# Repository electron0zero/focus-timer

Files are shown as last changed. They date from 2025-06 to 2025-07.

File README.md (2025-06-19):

# Focus Timer

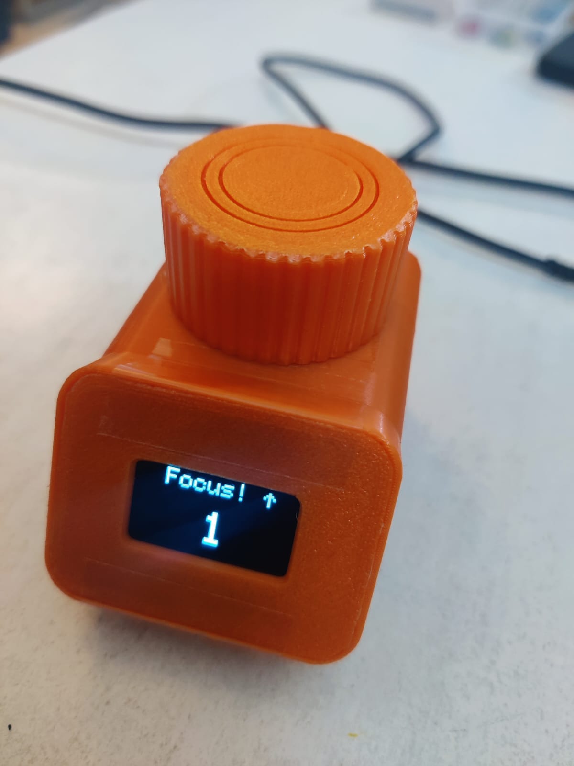
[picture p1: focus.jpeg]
Flow Counter showing focus minutes
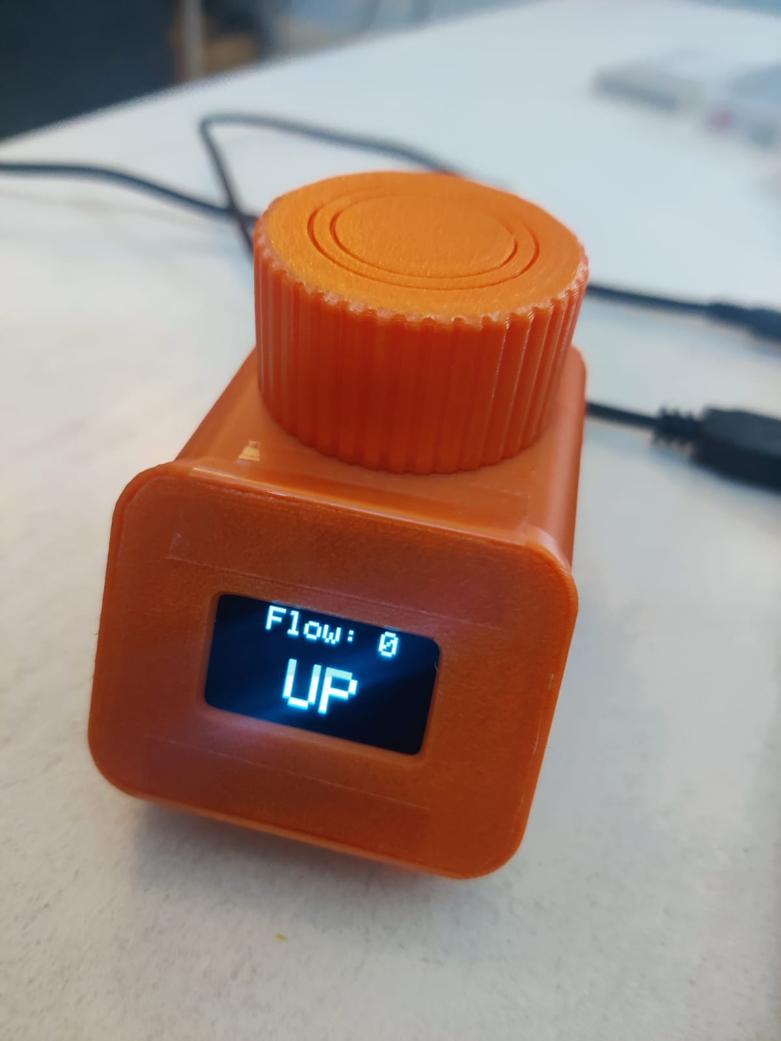
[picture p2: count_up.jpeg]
Flow Counter showing up counting
 

A customized version of [Project IGOR](https://github.com/UrbanCircles/igor), modified to suit my personal preferences and needs and the components I can easily find in major Indian hobby and electronics websites.

This is mostly the same as the original IGOR project, but with some tweaks to code and the PIN mapping for my specific hardware setup.

If you want to build your own version, you can use this as a starting point.

This would cut down the trial and error time for you, if your hardware is different from the original project and more close to mine.

## Features

Mostly same as the original IGOR project, with some minor tweaks, [see original](https://github.com/UrbanCircles/igor#its-simple-features-v1)

See this [video from the original project](https://www.youtube.com/watch?v=Wko0zgRGtPI) for a demo of the features.

## Hardware
- D1 Mini (ESP8266) - Sourced from robu.in
- 0.96" OLED Display (SSD1306)
- Rotary Encoder (HW-040)

## BOM

| Component | Quantity | Price (INR) | Robu.in Item and Link |
|---|---|---|---|
| D1 Mini (ESP8266) | 1 | ₹ 182.00  | D1 Mini V2 NodeMcu 4M Bytes Lua WIFI Internet Of Things Development Board Based ESP8266 - [link](https://robu.in/product/d1-mini-v2-nodemcu-4m-bytes-lua-wifi-internet-of-things-development-board-based-esp8266/) |
| 0.96" OLED Display (SSD1306) | 1 | ₹ 240.00 | 0.96″ OLED Display Module – SPI/I2C – 128×64 – 7 Pin (Blue) - [link](https://robu.in/product/0-96-oled-display-module/) |
| Rotary Encoder (HW-040) | 1 | ₹ 49.00 | M274 360 Degree Rotary Encoder Brick Sensor Module - [link](https://robu.in/product/m274-360-degree-rotary-encoder-module-brick-sensor/)  |
| Jumper Wires (Dupont) | 1 | ₹ 145.53 | 20 CM 40 Pin Dupont Cable Male/Male, Male/Female, Female/Female Cable Combo - [link](https://robu.in/product/20-cm-40-pin-dupont-male-male-male-female-female-female-cable-combo/) |

Total BOM Cost: ₹ 616.53 INR

> NOTE: to encoder I bought doesn't have a screw on the stem and it required a standoff to make it work, so if you don't want the hassle, buy an encoder that has a screw on stem so you can screw it to the box. it makes it easy to assemble and way better then the standoff workaround.

**Miscellaneous Items**

Breadboard, Jumper Wires(Dupont), 10k OHM resister, Soldering Station, etc.

## Pin Mapping and Wiring

The pin mapping is as follows:

#### OLED Pin Mapping

| OLED Pin | D1 Mini Pin | Comments |
|---|---|---|
| GND | G (GND) | Ground |
| VDD | 3V3 | Power supply (use 3.3V only) |
| SCK | D5 | SPI Clock — hardware SPI line, do not reuse |
| SDA | D7 | SPI Data — hardware SPI line, do not reuse |
| RES | D6 | OLD reset PIN |
| DC | D3 | Has pull-up; LOW at boot can cause boot issues — OK with INPUT_PULLUP |
| CS | D8 | Must be LOW at boot — OLED CS is typically LOW anyway |

#### Rotary Encoder Pin Mapping

| Encoder Pin | D1 Mini Pin | Comments |
|---|---|---|
| CLK | D1 | INT-capable — safe |
| DT | D2 | INT-capable — safe |
| SW | D0 | No internal pull-up — needs external 10KΩ pull-up |

**NOTE**
- Don't use D4, it's connected to the onboard blue LED so leave D4 Pin unused to not interfere with the built in LED.
- Don’t use D7, D5 for anything other than SPI for OLED when using hardware SPI. this OLED breakout board uses hardware SPI, so you must use the same pins as shown above.

#### wiring diagram

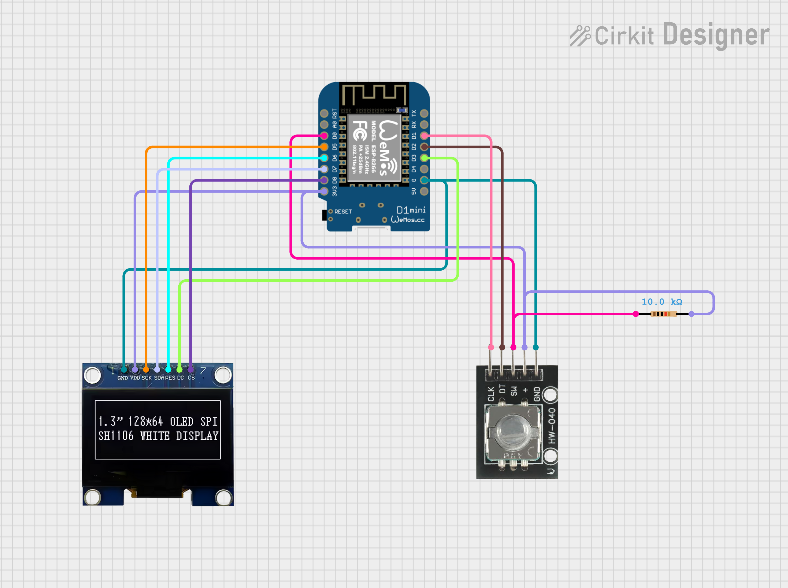
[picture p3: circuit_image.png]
wiring image


See [Focus Timer Wiring](https://app.cirkitdesigner.com/project/0dea471c-eeaa-448d-815e-7a7b2d2015ea) cirkitdesigner project for interactive wiring diagram.

## Microcontroller firmware

Load the firmware from the focus_timer.ino file into your D1 Mini (ESP8266) using the Arduino IDE.

Watch this video to see how to setup Arduino IDE for ESP8266: [Get Started With A D1 Mini (ESP8266) In Under 5 Minutes!](https://www.youtube.com/watch?v=WnRk8w7SyTo)

If the firmware does not work as expected, or some components are not working, you can try to [debug_code](./debug_code/) firmware and try to debug with logs in the serial monitor in the Arduino IDE.

## 3D Printed Parts - Case

I used a [3D files](https://github.com/UrbanCircles/igor/tree/main/3D%20Parts) from the original project, and printed it on my printer.

Same file can be found on [Printables](https://www.printables.com/model/1019283-project-igor-open-source-offline-loyal-cheerful-fo)

My encoder HW-040 didn't come with a screw stem to attach the encoder knob to the case, so I modelled a custom standoff to keep the encoder pcb in place and allow the encoder knob to be attached to the case.

if you want to print the standoff, you can find stl file in the repo, along with the [openSCAD](https://openscad.org/index.html) file to modify it if needed: [hw-040-standoff.scad](./hw-040-standoff.scad) and [hw-040-standoff.stl](./hw-040-standoff.stl)

If you don't own a 3D printer, ask your friends who have one or use 3D printing services from robu.in or other similar websites.

## Assembly & User Guide

See Original [Assembly](https://github.com/UrbanCircles/igor#assembly) and [guide](https://github.com/UrbanCircles/igor#user-guide)

## Credits

Most of the code is from [Project IGOR by UrbanCircles](https://github.com/UrbanCircles/igor) with some modifications by me.

The original project is licensed under the MIT License, my debugging code and modifications are also licensed under the MIT License.

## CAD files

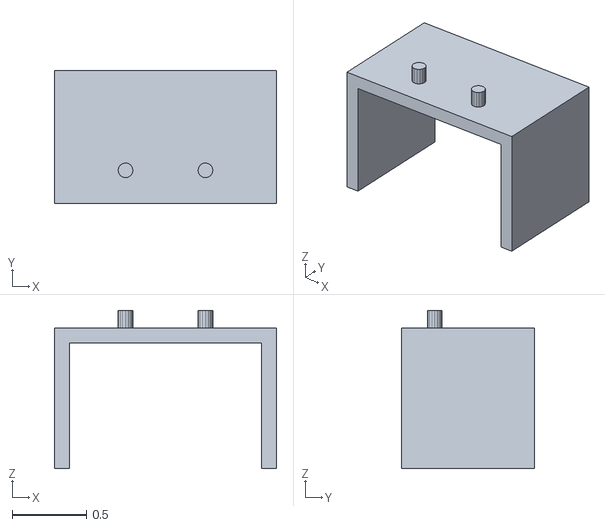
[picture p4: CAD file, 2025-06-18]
hw-040-standoff.stl
1.50 x 0.9 x 1.07

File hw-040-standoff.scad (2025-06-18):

// Parameters
leg_width = 0.10;           // Width of each leg
leg_depth = 0.90;           // Depth/thickness of each leg
leg_spacing = 1.3;         // Space between the two legs
table_height = 0.85;      // Height of the table top
top_thickness = 0.10;       // Thickness of the tabletop
pin_diameter = 0.10;       // Diameter of the alignment pins
pin_spacing = 0.54;        // Center-to-center spacing between pins
pin_height = 0.12;          // Height of alignment pins

// Build each leg
module leg(x_offset) {
    translate([x_offset, 0, 0])
        cube([leg_width, leg_depth, table_height]);
}

// Build tabletop
module tabletop() {
    translate([0, 0, table_height])
        cube([2 * leg_width + leg_spacing, leg_depth, top_thickness]);
}


// Build alignment pins on top
module pin(x_offset) {
    translate([x_offset, leg_depth * (1/4), table_height + top_thickness])
        cylinder(h = pin_height, d = pin_diameter, $fn = 16);
}


// Assemble standoff
union() {
    leg(0);
    leg(leg_width + leg_spacing);
    tabletop();

    // Pins, centered on tabletop
    pin((2 * leg_width + leg_spacing) / 2 - pin_spacing / 2);
    pin((2 * leg_width + leg_spacing) / 2 + pin_spacing / 2);
}

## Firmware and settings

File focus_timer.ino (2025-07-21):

#include <SPI.h>
#include <Adafruit_GFX.h>
#include <Adafruit_SSD1306.h>

//=========================================
// Hardware PIN Definitions / Mappings
// NOTE: make sure harware wiring matches this pin mapping

// OLED pin mapping for Display with Driver IC: SSD1306
// Display Source: https://robu.in/product/0-96-oled-display-module/#tab-description
// In my testing it only supports SPI and I2C doesn't work even tho it says I2C is supported.
//
// Pin connections for SPI
// | OLED Pin   | ESP8266 Pin | Notes                |
// | ---------- | ----------- | -------------------- |
// | GND        | GND         | Ground               |
// | VDD        | 3.3V        | Power (3.3V)         |
// | SCK (CLK)  | D5 (GPIO14) | SPI Clock            |
// | SDA (MOSI) | D7 (GPIO13) | SPI Data             |
// | RES        | D6 (GPIO12) | Reset                |
// | DC         | D3 (GPIO0)  | Data/Command select  |
// | CS         | D8 (GPIO15) | Chip select          |
//
// Don’t use D7, D5 for anything other than SPI for OLED when using hardware SPI.
// we are using hardware SPI, so you must not interfere with D5 (SCK) and D7 (MOSI),
// which are automatically used by SPI.
//
// see https://lastminuteengineers.com/wemos-d1-mini-pinout-reference/ for the details
// on which can be used for what, and why.

// Working pin setup for OLED without interfering with the encoder pins and onboard LED
// Don't use D4, it's connected to the onboard blue LED so leave D4 Pin unused
#define OLED_CLK    D5  // GPIO14
#define OLED_MOSI   D7  // GPIO13
#define OLED_RESET  D6  // GPIO12 — safe
#define OLED_DC     D3  // GPIO0 — safe if pulled HIGH at boot (default with pull-up)
#define OLED_CS     D8  // GPIO15 — must be LOW at boot (OLED CS is typically LOW)

#define SCREEN_WIDTH 128
#define SCREEN_HEIGHT 64

// Init the disaply lib
Adafruit_SSD1306 display(SCREEN_WIDTH, SCREEN_HEIGHT,
                         &SPI, OLED_DC, OLED_RESET, OLED_CS);

// Rotary Encoder pin definitions (no conflict with OLED PINS)
// #define ENC_SW   D4  // GPIO2 (needs to be HIGH at boot, connected to FLASH button, boot fails if pulled LOW)
//
// D4 Pin is hard-wired to on board LED so each time the SW is pressed, the LED will on turned on.
// it can be a feature or a bug, I liked that it's indicating button press but you may not want that.
// if you don't want, use D0 ping with a pull up register to disable the onboard LED.
//
// IMP. NOTE for ENC_SW when using PIN D0: make sure the use a 10k pull up resister between SW and VCC (+ pin)
// of the encoder to pull SW pin high otherwise the button press will make SW LOW and it will be stuck LOW
#define ENC_SW   D0  // GPIO16 (no INT, OK for polling), needs a 10K register as pull up with 3.3V
#define ENC_DT   D2  // GPIO4 (INT-capable, safe)
#define ENC_CLK  D1  // GPIO5 (INT-capable)


//=========================================
int flowMinutes = 0;   // Total flow minutes
int menuIndex = 0;     // 0 for UP, 1 for DOWN, 2 for Reset
String menuOptions[3] = {"UP", "DOWN", "Reset"};  // Label reset option as "Reset"
// for IDLE mode detection and display IDLE? text
unsigned long lastActivityTime = 0;  // For inactivity detection
const unsigned long inactivityLimit = 2 * 60000;  // 2 minutes in milliseconds

enum State { MENU, COUNTING_UP, COUNTING_DOWN, SELECTING_DOWN_DURATION, IDLE };
State currentState = MENU;

int countdownValue = 50;  // Default value for countdown
int initialCountdownValue = 50;  // Store the countdown value when selected
unsigned long previousMillis = 0;  // For counting logic
int elapsedMinutes = 0;
bool isCounting = false;

// IDLE mode extended behavior, display is turned off if we are in IDLE mode for 5 mins
const unsigned long displayOffTimeLimit = 5 * 60000;  // 5 minutes in milliseconds

unsigned long idleStartTime = 0;  // Track when IDLE mode starts
bool displayOff = false;  // Track if the display is off

// counter to know if the encoder was rotated or not, with direction
// We use following values:
// Clockwise = 1
// Counter Clockwise = -1
// No Rotation = 0
volatile int rotation = 0;
volatile bool rotated = false;
// volatile int counter = 0;

// Rotary encoder debounce variables
unsigned long lastInterruptTime = 0;
const unsigned long debounceDelay = 10;  // ms

// unsigned long lastRotaryTime = 0;
// const unsigned long rotaryDebounceDelay = 150;  // Faster debounce for rotary encoder

// Push button debounce and last state
unsigned long lastButtonDebounceTime = 0;
const unsigned long buttonDebounceDelay = 10;  // ms

// unsigned long buttonDebounceTime = 0;
// const unsigned long buttonDebounceDelay = 800;  // Debounce delay

volatile int lastClkState = HIGH;
volatile int lastDtState = HIGH;
bool lastButtonState = HIGH;

//=========================================
// Detect encoder rotation with Interrupts and debounce

void ICACHE_RAM_ATTR handleRotationState() {
  int clkState = digitalRead(ENC_CLK);
  int dtState = digitalRead(ENC_DT);

  // Only act when CLK changes and don't act on each Interrupt trigger
  if (clkState != lastClkState) {
    if (dtState != clkState) {
      // clockwise rotation happened
      rotation = 1;
      // counter++;
    } else {
      // counter clockwise rotation happened
      rotation = -1;
      // counter--;
    }
    rotated = true;
  }

  // Serial.print("Last ENC_DT: ");
  // Serial.print(lastDtState);
  // Serial.print(" ENC_DT: ");
  // Serial.print(dtState);
  // Serial.print(" Last ENC_CLK: ");
  // Serial.print(lastClkState);
  // Serial.print(" ENC_CLK: ");
  // Serial.print(clkState);
  // Serial.print(" counter: ");
  // Serial.println(counter);
  // Serial.print(" rotation: ");
  // Serial.println(rotation);
  // Serial.print(" rotated: ");
  // Serial.println(rotated);

  lastClkState = clkState;
  lastDtState = dtState;
}

void setup() {
  Serial.begin(115200);
  initEncoder();
  // attach Interrupt for encoder pins and handleRotationState
  attachInterrupt(digitalPinToInterrupt(ENC_CLK), handleRotationState, CHANGE);
  initDisplay();
  updateDisplay();

  Serial.println("Setup complete, starting loop...");
}

void loop() {
  unsigned long currentMillis = millis();

  // Handle rotary encoder input
  // rotation state is handled by handleRotation, called by Interrupt
  handleRotaryInput();

  // Handle button presses and states
  handleButtonPresses(currentMillis);

  // Handle counting logic
  handleCounting(currentMillis);

  // disable the idle mode feature
  // Handle inactivity
  handleInactivity(currentMillis);

  // reset rotation variables
  if (rotated) {
    rotated = false;
    // reset the rotation state if we rotated
    rotation = 0;
  }
}

//=========================================================
// Initialize hardware pins, and initialize the OLED display
void initEncoder() {
  // init encoder pins
  pinMode(ENC_SW, INPUT_PULLUP);
  pinMode(ENC_DT, INPUT_PULLUP);
  pinMode(ENC_CLK, INPUT_PULLUP);

  // log init state of encoder pins
  Serial.println("");
  Serial.println("Starting up...");
  Serial.print("Initial ENC_SW: ");
  Serial.println(digitalRead(ENC_SW)); // Should be HIGH with pullup
  Serial.print("Initial ENC_DT: ");
  Serial.println(digitalRead(ENC_DT)); // Should be HIGH with pullup
  Serial.print("Initial ENC_CLK: ");
  Serial.println(digitalRead(ENC_CLK)); // Should be HIGH with pullup

}

void initDisplay() {
  if (!display.begin(SSD1306_SWITCHCAPVCC, 0x3C)) {
    Serial.println("SSD1306 init failed");
    for (;;); // Halt
  }
  Serial.println("Display initialized.");

  // print READY for 1s to show that it's ready
  display.clearDisplay();
  display.setTextSize(4); // Large text
  display.setTextColor(WHITE);
  display.setCursor(0, 20); // print the text center of display
  display.println("READY");
  display.display();

  // wait 1 second with ready before we clear the display
  delay(1000);
  display.clearDisplay();
}

//=========================================================
// Update the OLED display with the current state
void updateDisplay() {
  display.setTextColor(WHITE);
  display.clearDisplay();

  // Display top row
  String topRowText;

  if (currentState == COUNTING_UP) {
    topRowText = "Focus! \x18";  // Focus with upward triangle for counting UP
  } else if (currentState == COUNTING_DOWN) {
    topRowText = "Focus! \x19";  // Focus with downward triangle for counting DOWN
  } else {
    // Display total flow minutes as hours and mins when not counting
    int hours = flowMinutes / 60;
    int minutes = flowMinutes % 60;
    char buffer[16];
    // using snprintf to padd the hour and seconds
    snprintf(buffer, sizeof(buffer), "Flow %02d:%02d", hours, minutes);
    topRowText = String(buffer);
  }

  int topRowTextWidth = topRowText.length() * 12;  // TextSize 2, so 12 pixels per char
  int topRowX = (128 - topRowTextWidth) / 2;  // Center the text on the top row

  display.setTextSize(2);  // Larger size for top row
  display.setCursor(topRowX, 0);  // Centered on top row
  display.print(topRowText);

  // Display main row (menu or counting values)
  String mainRowText;

  if (currentState == MENU) {
    mainRowText = menuOptions[menuIndex];  // Display UP, DOWN, or Reset in the menu
  } else if (currentState == COUNTING_UP) {
    mainRowText = String(elapsedMinutes);  // Display counting up minutes
  } else if (currentState == COUNTING_DOWN || currentState == SELECTING_DOWN_DURATION) {
    mainRowText = String(countdownValue);  // Display countdown minutes
  } else if (currentState == IDLE) {
    mainRowText = "IDLE?";
  }

  int mainRowTextWidth = mainRowText.length() * 24;  // TextSize 4, so 24 pixels per char
  int mainRowX = (128 - mainRowTextWidth) / 2;  // Calculate centered X position

  display.setTextSize(4);  // Larger size for main row
  display.setCursor(mainRowX, 30);  // Centered on main row
  display.print(mainRowText);

  display.display();  // Show the updated display
}

//===========================================
// Detect encoder button presses with debounce
bool buttonPressed() {
  bool currentState = digitalRead(ENC_SW);
  // Serial.print("called buttonPressed, currentState: ");
  // Serial.println(currentState);

  if (lastButtonState == HIGH && currentState == LOW && (millis() - lastButtonDebounceTime > buttonDebounceDelay)) {
    Serial.println("push button pressed...");
    lastButtonDebounceTime = millis();
    lastButtonState = currentState;
    return true;
  }

  lastButtonState = currentState;
  return false;
}

//=========================================================
// Handle button presses and manage state transitions
void handleButtonPresses(unsigned long currentMillis) {
  if (!buttonPressed()) return;

  switch (currentState) {
    case MENU:
      if (menuIndex == 0) {  // UP selected
        startCountingUp();
      } else if (menuIndex == 1) {  // DOWN selected
        startSelectingDownDuration();
      } else if (menuIndex == 2) {  // Reset selected
        resetFlowMinutes();  // Reset the total focus time to 0
      }
      break;

    case SELECTING_DOWN_DURATION:
      confirmCountdownSelection();
      break;

    case COUNTING_UP:
      stopCountingUp();
      break;

    case COUNTING_DOWN:
      stopCountingDown();
      break;
  }
  updateDisplay();
}

//=========================================================
// Start counting up
void startCountingUp() {
  currentState = COUNTING_UP;
  elapsedMinutes = 0;
  isCounting = true;
  lastActivityTime = millis();  // Reset inactivity timer
  selectConfirm();
  Serial.println("Counting UP started.");
}

//=========================================================
// Start selecting the countdown duration
void startSelectingDownDuration() {
  currentState = SELECTING_DOWN_DURATION;
  countdownValue = 50;
  lastActivityTime = millis();  // Reset inactivity timer
  Serial.println("Selecting DOWN duration.");
}

//=========================================================
// Confirm countdown selection and start counting down
void confirmCountdownSelection() {
  initialCountdownValue = countdownValue;
  currentState = COUNTING_DOWN;
  isCounting = true;
  selectConfirm();
  lastActivityTime = millis();  // Reset inactivity timer
  Serial.print("Counting DOWN started with "); Serial.print(countdownValue); Serial.println(" minutes.");
}

//=========================================================
// Stop counting up and return to menu
void stopCountingUp() {
  flowMinutes += elapsedMinutes;
  successAnimation();
  currentState = MENU;
  isCounting = false;
  Serial.println("Counting UP stopped. Returning to MENU.");
}

//=========================================================
// Stop counting down and return to menu
void stopCountingDown() {
  flowMinutes += (initialCountdownValue - countdownValue);
  successAnimation();
  currentState = MENU;
  isCounting = false;
  Serial.println("Counting DOWN stopped. Returning to MENU.");
}

//=========================================================
// Reset the total flow minutes counter to 0
void resetFlowMinutes() {
  flowMinutes = 0;
  Serial.println("Flow minutes reset to 0.");
  successAnimation();
  updateDisplay();  // Update the display to show the reset value
}

//=========================================================
// Handle counting up or down logic
void handleCounting(unsigned long currentMillis) {
  // no-op if we are not counting or 1 minute has not passed since we counted
  if (!isCounting || (currentMillis - previousMillis < 60000)) return;

  previousMillis = currentMillis;

  if (currentState == COUNTING_UP) {
    elapsedMinutes++;
    updateDisplay();
    Serial.print("Counting UP: "); Serial.println(elapsedMinutes);
  } else if (currentState == COUNTING_DOWN) {
    countdownValue--;
    if (countdownValue <= 0) {
      flowMinutes += initialCountdownValue;
      successAnimation();
      currentState = MENU;
      isCounting = false;
      Serial.println("Countdown finished, returning to MENU.");
    }
    updateDisplay();
    Serial.print("Counting DOWN: "); Serial.println(countdownValue);
  }
}

//=========================================================
// Success animation when a session ends
void successAnimation() {
  display.clearDisplay();
  int centerX = 64, centerY = 32;

  for (int radius = 2; radius <= 30; radius += 2) {
    display.drawCircle(centerX, centerY, radius, WHITE);
    display.display();
    delay(40);

    if (radius % 4 == 0) {
      display.clearDisplay();
      display.display();
      delay(2);
    }
  }

  display.clearDisplay();
  display.setTextSize(2);
  display.setCursor(20, 20);
  display.print("SUCCESS!");
  display.display();
  delay(1000); // 1 seconds
  display.clearDisplay();
  display.display();
}

void selectConfirm() {
  display.clearDisplay();
  display.setTextSize(2);
  display.setCursor(10, 20);
  display.print("SELECTED!");
  display.display();
  delay(1000); // 1 seconds
  display.clearDisplay();
  display.display();
}

//=========================================================
// Handle rotary input for menu and countdown selection
// this is not my code, I need to modify my rotation code to adopt this.
void handleRotaryInput() {
  if (rotation == 0) return;  // No rotation detected

  // IDLE mode feature disabled
  lastActivityTime = millis();  // Reset inactivity timer on any valid rotation
  Serial.print(millis());  // Print the current time in milliseconds
  Serial.print(" - Rotation detected, activity timer reset. Rotation: ");
  Serial.println(rotation);

  if (currentState == MENU) {
    menuIndex = (menuIndex + rotation + 3) % 3;  // Update for 3 menu options: UP, DOWN, Reset
    updateDisplay();
    Serial.print(millis());  // Print the current time in milliseconds
    Serial.print(" - Menu option: "); Serial.println(menuOptions[menuIndex]);
  } else if (currentState == SELECTING_DOWN_DURATION) {
    // handle the increase and decrease in the down minutes
    // increase or decrease the countdown value in the steps of 5 mins
    countdownValue = max(1, countdownValue + (rotation * 5));
    updateDisplay();
    Serial.print(millis());  // Print the current time in milliseconds
    Serial.print(" - Countdown value: "); Serial.println(countdownValue);
  }
}

//=========================================================
// Handle inactivity and switch to IDLE if necessary
void handleInactivity(unsigned long currentMillis) {
  // Comment out frequent serial prints to improve performance
  // Serial.print(millis());
  // Serial.print(" - Current time (millis): ");
  // Serial.println(currentMillis);

  // Serial.print(millis());
  // Serial.print(" - Last activity time (millis): ");
  // Serial.println(lastActivityTime);

  // Make sure the subtraction does not cause an overflow/underflow
  if (currentMillis >= lastActivityTime) {
    unsigned long timeSinceLastActivity = currentMillis - lastActivityTime;

    // Serial.print(millis());
    // Serial.print(" - Time since last activity (ms): ");
    // Serial.println(timeSinceLastActivity);

    // Check if the user is in the MENU or selecting countdown duration mode
    if ((currentState == MENU || currentState == SELECTING_DOWN_DURATION) && (timeSinceLastActivity > inactivityLimit)) {
      if (currentState != IDLE) {
        currentState = IDLE;
        idleStartTime = millis();  // Record when IDLE mode starts
        updateDisplay();
        Serial.print(millis());  // Print the current time in milliseconds
        Serial.println(" - IDLE state entered due to inactivity.");
      }
    }
  } else {
    // Comment out warning to reduce unnecessary serial prints
    // Serial.println(" - Warning: currentMillis is less than lastActivityTime!");
  }

  // Check if the user has been in IDLE for more than displayOffTimeLimit and turn off the display
  if (currentState == IDLE && !displayOff && (currentMillis - idleStartTime > displayOffTimeLimit)) {
    displayOff = true;
    display.ssd1306_command(SSD1306_DISPLAYOFF);  // Turn off the display
    Serial.print(millis());  // Print the current time in milliseconds
    Serial.println(" - Display turned off after it reached display off time limit.");
  }

  // Exit IDLE if any rotary or button action happens
  if (currentState == IDLE && (rotation != 0 || buttonPressed())) {
    currentState = MENU;
    lastActivityTime = millis();  // Reset inactivity timer upon exiting IDLE

    // Turn the display back on if it was off
    if (displayOff) {
      display.ssd1306_command(SSD1306_DISPLAYON);
      displayOff = false;
      Serial.print(millis());  // Print the current time in milliseconds
      Serial.println(" - Display turned back on.");
    }

    updateDisplay();
    Serial.print(millis());  // Print the current time in milliseconds
    Serial.println(" - Exiting IDLE mode. Back to MENU.");
  }
}

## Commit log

2025-06-16 Program for testing OLED and it's pin connections
2025-06-16 Update readme with wiring diagram
2025-06-16 Add code to debug OLED and encoder combined
2025-06-18 scad model for the standoff for the encoder
    [hw-040-standoff.scad, hw-040-standoff.stl]
2025-06-18 README.md entry for the standoff
2025-06-18 update the standoff model
    [hw-040-standoff.scad, hw-040-standoff.stl]
2025-06-19 add images and note about encoder stem issue
2025-07-21 format flow time in hours and mins instead of just mins
